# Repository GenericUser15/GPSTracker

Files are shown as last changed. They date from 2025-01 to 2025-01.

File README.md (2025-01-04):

# GPS Tracker

After having to cancel vet appointments because my cats were gallivanting somewhere outside, I decided to build a GPS tracking collar. These already exist but I wanted to create a fully open sourced version. I'm an embedded software engineer so my PCB knowledge is lacking, I'm much more software orientated! The PCB has been designed on KiCad.

# Architecture

The device uses a U-BLOX SARA-N310 LTE module, U-BLOX ZOE-M8G GPS module, an embedded SIM card and an STM32L011 to control everything.

The ST uses two UART lines to communicate with the GPS device and the LTE device. The GPS device will output NMEA messages by default but both lines are connected in case there is a requirement to modify any of the default settings.

The LTE device is controlled with AT commands and will communicate with the SIM card by itself.

The LTE device will then send GPS data to an endpoint, the UI can then pick up this data and overlay it on a map.

The idea is to keep everything in a deep sleep mode as much as possible, only waking to send some data. This is to reduce power consumption as much as possible. 

I'm not decided on how often to update the GPS. Maybe it can be geo-fenced so that it will update at a low rate (once a minute?) if the device hasn't left the house. Otherwise, update every 10 seconds. This will need some discussion and testing. Power consumption will come into this decision too.

# UI

I haven't given the UI much thought or how it would even work. This is something that needs to be discussed. It should have a map overlay which will plot where the cat has been over a ime period that the user can select. It should also be able to plot the current location.

# Hardware

A big consideration for this project is power usage and footprint. The smaller and lighter the PCB, the better. A small device is less likely to get stuck in something, making the collar snap free. Also, some cats may find it annoying if it's a bit bulky. The GPS and ST have been chosen for their low current draw. 

I would like to make the whole thing waterproof is possible, or at least water resistant. Who knows what crazy situations cats get into! 

I have included lots of test points but these can be removed in the final design.

# Antennas

The GPS antenna will be a small puck antenna. The device will naturally sit under a cats neck, this is going to be a problem for GPS! I don't know if the antenna will be sensitive enough to pick up GPS data bouncing off of the ground, this is something that could be tested. It this isn't an option, perhaps the whole thing could be integrated into a collar as one unit, with the antenna running up inside the collar.

I haven't given the LTE antenna much thought, it would be really nice to have it designed into the PCB but I don't know enough about antenna design to do this. The current design is for an external antenna with a UFL connection. Hopefully there is an antenna small enough to fit!

# Software

I planned to use the HAL for the ST, the software shouldn't be that complicated and using the HAL will make it much easier to get this up and running. 

There needs to be a server somewhere to provide the front end and store some historic GPS data. This should be a full stack app that can be accessed from anywhere. The front end needs a map of the world, on to which the position can be overlaid. There should be a "live" mode which just reads an endpoint, waiting for GPS data to come in and then updating the point on the map. 

The server should also store all GPS data so the user can login and plot where the device has been over a user defined period of time. This will allow the user to see where the device has been on a given day, week or longer.

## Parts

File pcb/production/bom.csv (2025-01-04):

Designator | Footprint | Quantity | Value | LCSC Part #
C1, C10, C11, C2 | 01005 | 4 | 1uF
C12, C16 | 01005 | 2 | 100nF
C13, C20 | 01005 | 2 | 10uF
C14, C19 | 01005 | 2 | 15pF
C15, C5, C6, C7, C8 | 01005 | 5 | 33pF
C17 | 01005 | 1 | 10nF
C18 | 01005 | 1 | 68pF
C3 | 01005 | 1 | 47pF
C4 | 01005 | 1 | 0.1uF
C9 | 01005 | 1 | 100uF
IC1 | SARAN31000X | 1 | SARA-N310-00X
IC2 | SON127P600X500X100-9N | 1 | ST4SI2M0020TPIFW
J1, J2 | U.FL_Hirose_U.FL-R-SMT-1_Vertical | 2 | Conn_Coaxial
L1 | 0402 | 1 | L_Iron
L2 | 0402 | 1 | 2.2uH
L3 | 0402 | 1 | 1uF
L4 | 0402 | 1 | 39nH
Q1, Q2 | SOT95P237X112-3N | 2 | SQ2318CES-T1_GE3
R1, R10, R16, R17, R18, R2, R21, R22, R6, R9 | 0201 | 10 | 10K
R11 | 0201 | 1 | 330K
R12 | 0201 | 1 | 50K
R3 | 0201 | 1 | 10
TP1, TP12_GND_OUT1 | TestPoint_THTPad_D1.0mm_Drill0.5mm | 2 | 3v3 In
TP10 | TestPoint_Pad_D1.0mm | 1 | TP_ST_UART2_RTS
TP11 | TestPoint_Pad_D1.0mm | 1 | TP_ST_UART2_CTS
TP2 | TestPoint_Pad_D1.0mm | 1 | TestPoint
TP3 | TestPoint_Pad_D1.0mm | 1 | TP_ST_UART1_TX
TP4 | TestPoint_THTPad_D1.0mm_Drill0.5mm | 1 | SWCLK
TP5 | TestPoint_THTPad_D1.0mm_Drill0.5mm | 1 | SWDIO
TP6 | TestPoint_Pad_D1.0mm | 1 | 1V8
TP7 | TestPoint_Pad_D1.0mm | 1 | TP_ST_UART1_RX
TP8 | TestPoint_Pad_D1.0mm | 1 | TP_ST_UART2_TX
TP9 | TestPoint_Pad_D1.0mm | 1 | TP_ST_UART2_RX
U1 | ST_UFQFPN-20_3x3mm_P0.5mm | 1 | STM32L011F3Ux
U2 | ublox_ZOE_M8 | 1 | ZOE-M8G
U3 | SOT-23-5 | 1 | LP5907MFX-1.8
U4 | SOT-23-6 | 1 | TLV61070ADBV
U7 | SOT-23 | 1 | MCP1703Ax-120xxTT
Y1 | Crystal_SMD_MicroCrystal_CM9V-T1A-2Pin_1.6x1.0mm_HandSoldering | 1 | Crystal

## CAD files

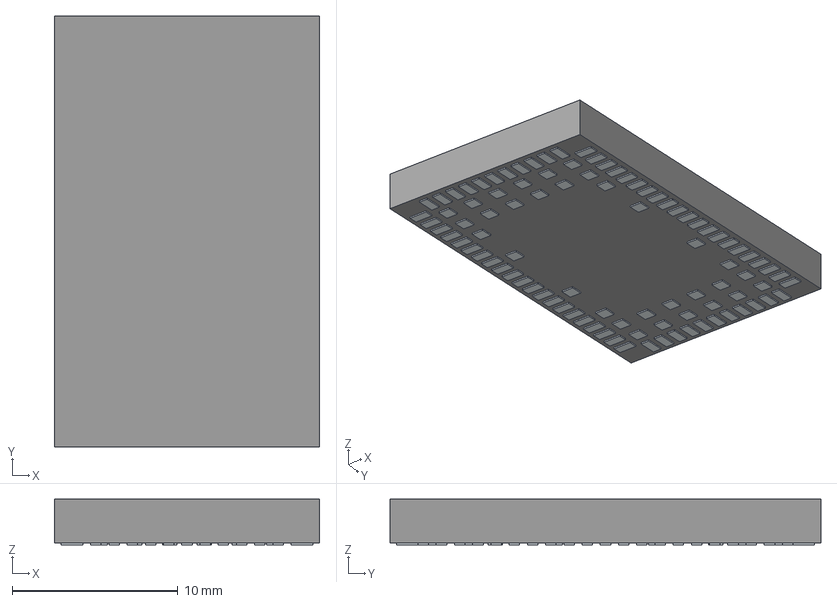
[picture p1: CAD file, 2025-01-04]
pcb/components/SARA-N310-00X/3D/SARA-N310-00X.stp
16.0 x 26.0 x 2.75 mm
Pins

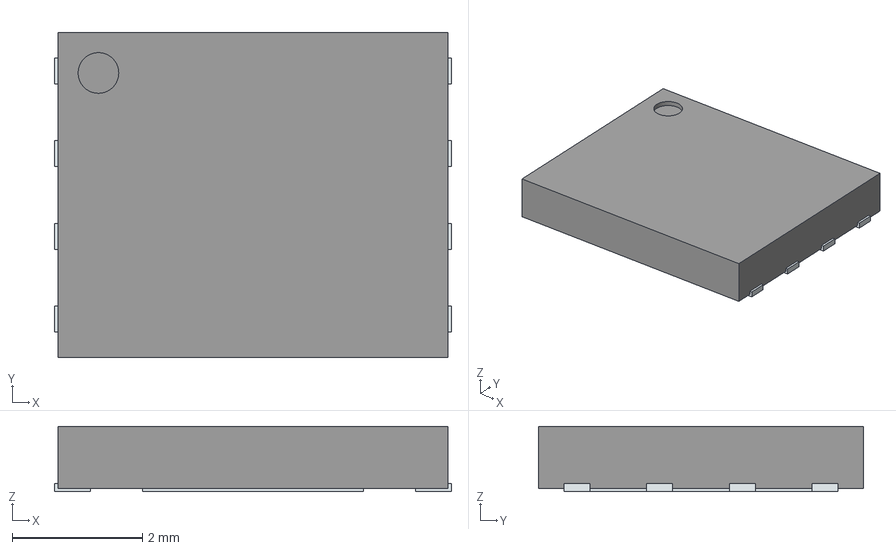
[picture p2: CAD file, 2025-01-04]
pcb/components/ST4SI2M0020TPIFW/3D/ST4SI2M0020TPIFW.stp
6.10 x 5.00 x 1.00 mm
ThermalPin
PinsArrayLR

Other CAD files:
pcb/components/SARA-N310-00X/Allegro/saran31000x.psm
pcb/components/SARA-N310-00X/DEHDL/sara_n310_00x/chips/chips.prt
pcb/components/ST4SI2M0020TPIFW/Allegro/son127p600x500x100-9n.psm
pcb/components/ST4SI2M0020TPIFW/DEHDL/st4si2m0020tpifw/chips/chips.prt

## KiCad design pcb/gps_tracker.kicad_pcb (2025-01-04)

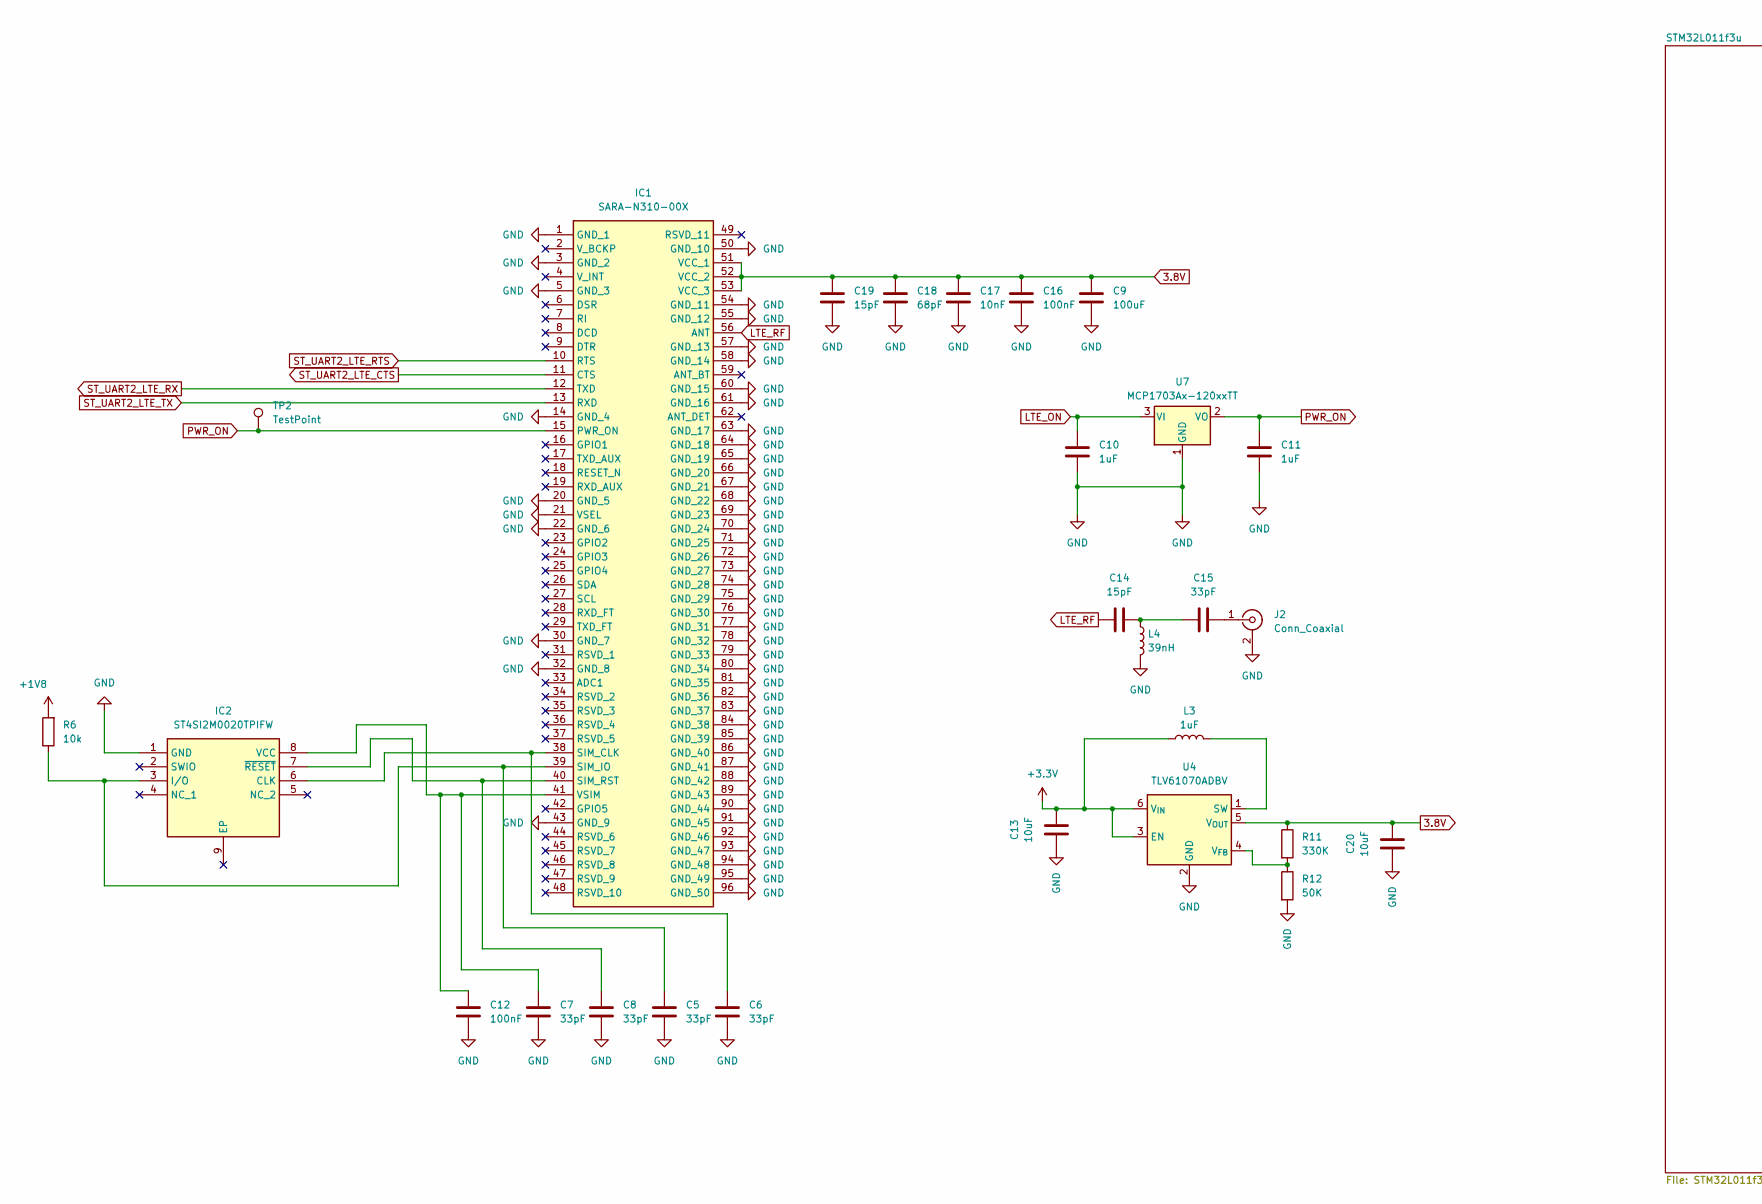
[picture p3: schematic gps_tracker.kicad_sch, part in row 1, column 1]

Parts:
C5, C6, C7, C8, C15: 33pF; C_01005_0402Metric_Pad0.57x0.30mm_HandSolder
C9: 100uF; C_01005_0402Metric_Pad0.57x0.30mm_HandSolder
C10, C11: 1uF; C_01005_0402Metric_Pad0.57x0.30mm_HandSolder
C12, C16: 100nF; C_01005_0402Metric_Pad0.57x0.30mm_HandSolder
C13, C20: 10uF; C_01005_0402Metric_Pad0.57x0.30mm_HandSolder
C14, C19: 15pF; C_01005_0402Metric_Pad0.57x0.30mm_HandSolder
C17: 10nF; C_01005_0402Metric_Pad0.57x0.30mm_HandSolder
C18: 68pF; C_01005_0402Metric_Pad0.57x0.30mm_HandSolder
IC1: SARA-N310-00X; SARAN31000X; Mouser Part Number 377-SARA-N310-00X
IC2: ST4SI2M0020TPIFW; SON127P600X500X100-9N; Mouser Part Number 511-ST4SI2M0020TPIFW
J2: Conn_Coaxial; U.FL_Hirose_U.FL-R-SMT-1_Vertical
L3: 1uF; L_0402_1005Metric_Pad0.77x0.64mm_HandSolder
L4: 39nH; L_0402_1005Metric_Pad0.77x0.64mm_HandSolder
R6: 10k; R_0201_0603Metric_Pad0.64x0.40mm_HandSolder
R11: 330K; R_0201_0603Metric_Pad0.64x0.40mm_HandSolder
R12: 50K; R_0201_0603Metric_Pad0.64x0.40mm_HandSolder
TP2: TestPoint; TestPoint_Pad_D1.0mm
U4: TLV61070ADBV; SOT-23-6
U7: MCP1703Ax-120xxTT; SOT-23

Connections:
3.8V: C9.1, C16.1, C17.1, C18.1, C19.1, C20.2, IC1.51 (VCC_1), IC1.52 (VCC_2), IC1.53 (VCC_3), R11.1, U4.5 (V_{OUT})
+1V8: R6.2; also elsewhere on the board
+3.3V: C13.2, L3.1, U4.3 (EN), U4.6 (V_{IN}); also elsewhere on the board
GND: C5.2, C6.2, C7.2, C8.2, C9.2, C10.2, C11.2, C12.2, C13.1, C16.2, C17.2, C18.2, C19.2, C20.1, IC1.1 (GND_1), IC1.3 (GND_2), IC1.5 (GND_3), IC1.14 (GND_4), IC1.20 (GND_5), IC1.21 (VSEL), IC1.22 (GND_6), IC1.30 (GND_7), IC1.32 (GND_8), IC1.43 (GND_9), IC1.50 (GND_10), IC1.54 (GND_11), IC1.55 (GND_12), IC1.57 (GND_13), IC1.58 (GND_14), IC1.60 (GND_15), IC1.61 (GND_16), IC1.63 (GND_17), IC1.64 (GND_18), IC1.65 (GND_19), IC1.66 (GND_20), IC1.67 (GND_21), IC1.68 (GND_22), IC1.69 (GND_23), IC1.70 (GND_24), IC1.71 (GND_25), IC1.72 (GND_26), IC1.73 (GND_27), IC1.74 (GND_28), IC1.75 (GND_29), IC1.76 (GND_30), IC1.77 (GND_31), IC1.78 (GND_32), IC1.79 (GND_33), IC1.80 (GND_34), IC1.81 (GND_35), IC1.82 (GND_36), IC1.83 (GND_37), IC1.84 (GND_38), IC1.85 (GND_39), IC1.86 (GND_40), IC1.87 (GND_41), IC1.88 (GND_42), IC1.89 (GND_43), IC1.90 (GND_44), IC1.91 (GND_45), IC1.92 (GND_46), IC1.93 (GND_47), IC1.94 (GND_48), IC1.95 (GND_49), IC1.96 (GND_50), IC2.1 (GND), J2.2 (Ext), L4.2, R12.2, U4.2 (GND), U7.1 (GND); also elsewhere on the board
LTE_ON: C10.1, U7.3 (VI); also elsewhere on the board
LTE_RF: C14.1, IC1.56 (ANT)
unnamed: C14.2, C15.1, L4.1
unnamed: C6.1, IC1.38 (SIM_CLK), IC2.6 (CLK)
unnamed: C5.1, IC1.39 (SIM_IO), IC2.3 (I/O), R6.1
unnamed: C8.1, IC1.40 (SIM_RST), IC2.7 (~RESET)
unnamed: C7.1, C12.1, IC1.41 (VSIM), IC2.8 (VCC)
unnamed: C15.2, J2.1 (In)
unnamed: L3.2, U4.1 (SW)
unnamed: R11.2, R12.1, U4.4 (V_{FB})
PWR_ON: C11.1, IC1.15 (PWR_ON), TP2.1, U7.2 (VO)
ST_UART2_LTE_CTS: IC1.11 (CTS); also elsewhere on the board
ST_UART2_LTE_RTS: IC1.10 (RTS); also elsewhere on the board
ST_UART2_LTE_RX: IC1.12 (TXD); also elsewhere on the board
ST_UART2_LTE_TX: IC1.13 (RXD); also elsewhere on the board

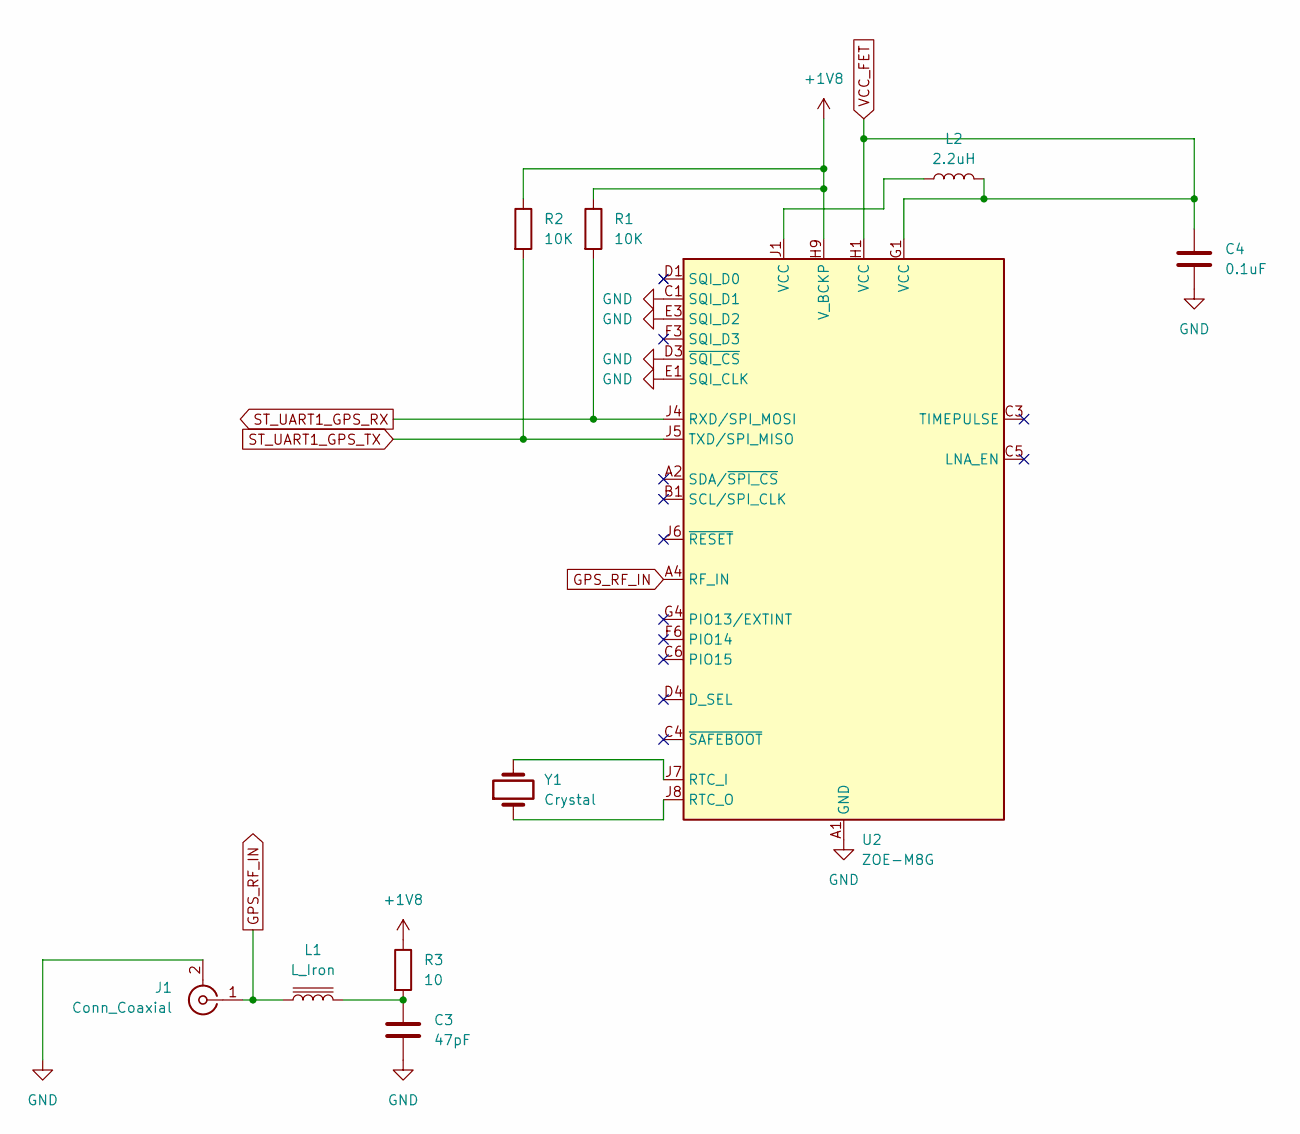
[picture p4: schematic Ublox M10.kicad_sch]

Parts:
C3: 47pF; C_01005_0402Metric_Pad0.57x0.30mm_HandSolder
C4: 0.1uF; C_01005_0402Metric_Pad0.57x0.30mm_HandSolder
J1: Conn_Coaxial; U.FL_Hirose_U.FL-R-SMT-1_Vertical
L1: L_Iron; L_0402_1005Metric_Pad0.77x0.64mm_HandSolder
L2: 2.2uH; L_0402_1005Metric_Pad0.77x0.64mm_HandSolder
R1, R2: 10K; R_0201_0603Metric_Pad0.64x0.40mm_HandSolder
R3: 10; R_0201_0603Metric_Pad0.64x0.40mm_HandSolder
U2: ZOE-M8G; ublox_ZOE_M8
Y1: Crystal; Crystal_SMD_MicroCrystal_CM9V-T1A-2Pin_1.6x1.0mm_HandSolder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

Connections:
+1V8: R1.1, R2.1, R3.1, U2.H9 (V_BCKP); also elsewhere on the board
GND: C3.2, C4.2, J1.2 (Ext), U2.A1 (GND), U2.A3 (GND), U2.A5 (GND), U2.A7 (GND), U2.A8 (GND), U2.A9 (GND), U2.B9 (GND), U2.C1 (SQI_D1), U2.C7 (GND), U2.C9 (GND), U2.D3 (~SQI_CS), U2.D6 (GND), U2.D9 (GND), U2.E1 (SQI_CLK), U2.E3 (SQI_D2), U2.E7 (GND), U2.F7 (GND), U2.G3 (GND), U2.G6 (GND), U2.G7 (GND), U2.J3 (GND), U2.J9 (GND); also elsewhere on the board
GPS_RF_IN: J1.1 (In), L1.1, U2.A4 (RF_IN)
unnamed: C3.1, L1.2, R3.2
unnamed: L2.1, U2.J1 (VCC), U2.J2 (VCC)
unnamed: U2.J7 (RTC_I), Y1.2
unnamed: U2.J8 (RTC_O), Y1.1
ST_UART1_GPS_RX: R1.2, U2.J4 (RXD/SPI_MOSI); also elsewhere on the board
ST_UART1_GPS_TX: R2.2, U2.J5 (TXD/SPI_MISO); also elsewhere on the board
VCC_FET: C4.1, L2.2, U2.G1 (VCC), U2.H1 (VCC); also elsewhere on the board

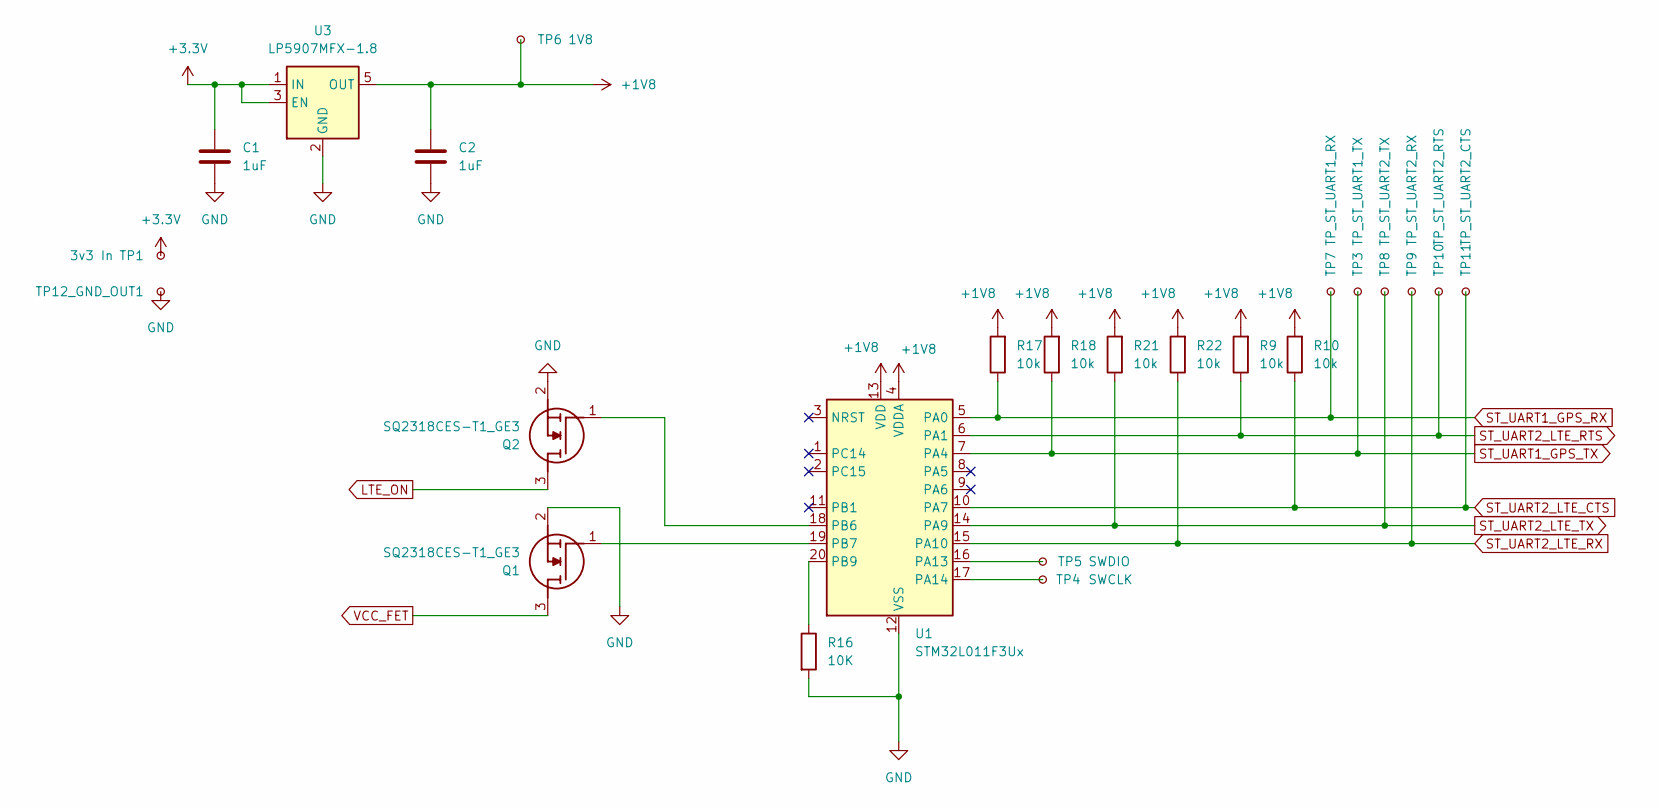
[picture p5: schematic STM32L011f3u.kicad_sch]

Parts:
C1, C2: 1uF; C_01005_0402Metric_Pad0.57x0.30mm_HandSolder
Q1, Q2: SQ2318CES-T1_GE3; SOT95P237X112-3N; Mouser Part Number 78-SQ2318CES-T1_GE3
R9, R10, R17, R18, R21, R22: 10k; R_0201_0603Metric_Pad0.64x0.40mm_HandSolder
R16: 10K; R_0201_0603Metric_Pad0.64x0.40mm_HandSolder
TP1, TP12_GND_OUT1: 3v3 In; TestPoint_THTPad_D1.0mm_Drill0.5mm
TP3: TP_ST_UART1_TX; TestPoint_Pad_D1.0mm
TP4: SWCLK; TestPoint_THTPad_D1.0mm_Drill0.5mm
TP5: SWDIO; TestPoint_THTPad_D1.0mm_Drill0.5mm
TP6: 1V8; TestPoint_Pad_D1.0mm
TP7: TP_ST_UART1_RX; TestPoint_Pad_D1.0mm
TP8: TP_ST_UART2_TX; TestPoint_Pad_D1.0mm
TP9: TP_ST_UART2_RX; TestPoint_Pad_D1.0mm
TP10: TP_ST_UART2_RTS; TestPoint_Pad_D1.0mm
TP11: TP_ST_UART2_CTS; TestPoint_Pad_D1.0mm
U1: STM32L011F3Ux; ST_UFQFPN-20_3x3mm_P0.5mm
U3: LP5907MFX-1.8; SOT-23-5

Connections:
+1V8: C2.1, R9.2, R10.2, R17.2, R18.2, R21.2, R22.2, TP6.1, U1.4 (VDDA), U1.13 (VDD), U3.5 (OUT); also elsewhere on the board
+3.3V: C1.1, TP1.1, U3.1 (IN), U3.3 (EN); also elsewhere on the board
GND: C1.2, C2.2, Q1.2 (S), Q2.2 (S), R16.2, TP12_GND_OUT1.1, U1.12 (VSS), U3.2 (GND); also elsewhere on the board
LTE_ON: Q2.3 (D); also elsewhere on the board
unnamed: Q1.1 (G), U1.19 (PB7)
unnamed: Q2.1 (G), U1.18 (PB6)
unnamed: TP5.1, U1.16 (PA13)
unnamed: TP4.1, U1.17 (PA14)
unnamed: R16.1, U1.20 (PB9)
ST_UART1_GPS_RX: R17.1, TP7.1, U1.5 (PA0); also elsewhere on the board
ST_UART1_GPS_TX: R18.1, TP3.1, U1.7 (PA4); also elsewhere on the board
ST_UART2_LTE_CTS: R10.1, TP11.1, U1.10 (PA7); also elsewhere on the board
ST_UART2_LTE_RTS: R9.1, TP10.1, U1.6 (PA1); also elsewhere on the board
ST_UART2_LTE_RX: R22.1, TP9.1, U1.15 (PA10); also elsewhere on the board
ST_UART2_LTE_TX: R21.1, TP8.1, U1.14 (PA9); also elsewhere on the board
VCC_FET: Q1.3 (D); also elsewhere on the board

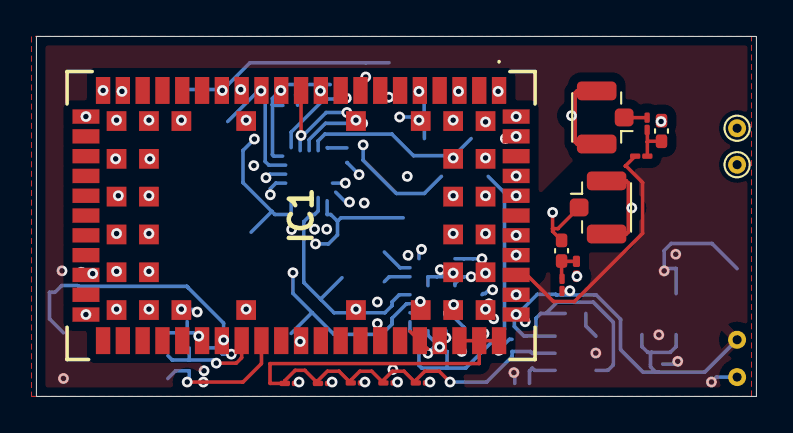
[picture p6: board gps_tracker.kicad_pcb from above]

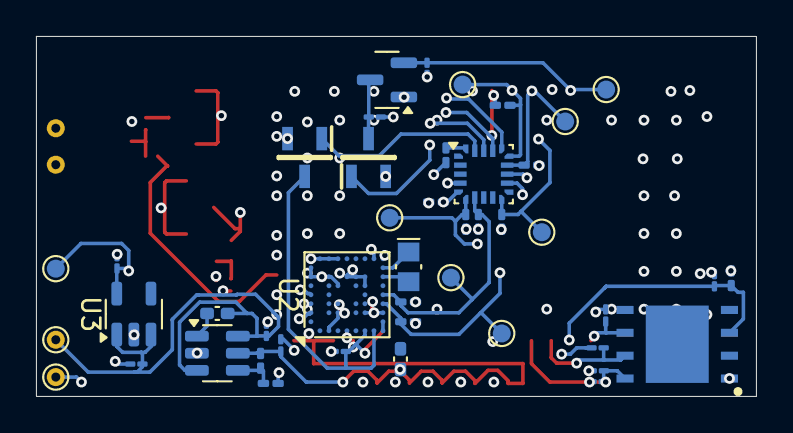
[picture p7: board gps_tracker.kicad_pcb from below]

Board: 6 copper layers, 40.0 x 20.0 mm, 61 parts (45 on the bottom side), 32 nets.
